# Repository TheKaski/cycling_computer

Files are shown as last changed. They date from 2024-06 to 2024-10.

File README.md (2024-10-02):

## Introduction

This project aims to offer way to turn your Arduino board into a basic cycling speedometer with the following measurement features implemented: Current speed, Average speed, Travelled distance and Cadence sensor. Additionally this project also offers 3D models for 3D printed parts including: casing of the board, casing of the sensor, holder for magnets. This code was implemented for the board: Arduino RP2040 Nano Connect with BLE support, but other boards should also be compatitible with the code with minor adjustments. Check the Hardware section for more details about my specific build.

## Contributors

<a href="https://github.com/TheKaski/cycling_computer/graphs/contributors">
  
</a>

## Supported Features

- **Speed Sensor**
- **Cadence Sensor**
- **7/8-Segment Display**
- **Current Speed**
- **Average Speed**
- **Travelled Distance**
- **BLE support for speed and cadence**

## Goals and outcomes of this project

The goals for this project were to:

1. Find interesting use case for Arduino board and develop a solution for that use case
2. Learn more about Arduino, C++ and electronics
3. Learn more about 3D printing and designing.

Outcome of this project is that I learned a lot about working with Arduino and electronics. I also learned a lot more about C++ as I decided to write the 7-segment display class from scratch. My skills on 3D printing and design were also improved by the project. I am particularily happy with the snap on bottom and top of the casing and the design which allows to print separately the bottom, casing and the top to make it easier to fit other components.

## How to use this project:

You can use this project by cloning this repo:

```
git clone https://github.com/TheKaski/cycling_computer.git
```

Open the file cycling_computer.ino with the Arduino IDE and upload to your board.
The Arduino codefile cycling_computer.ino uses the custom made display class for the segment display, however with small adjustments you can also configure the code to use any other display class if you want to. You can also try to develop your own display class inside the Display.cpp and .h files if you want to learn about Arduino, C++, Display libraries and Github contributions. However this is not expected by the nature of this project being only a hobby project. You can adjust the .ino file according to your needs relatively easily.

## Hardware used

Board: Arduino RP2040 Nano Connect

Battery: 9V battery

Hall effect sensor: Bipolar hall effect sensor SS441A

Display: Four digit segment display with decimal points(8-segments) 5611AS

PushButton: Momentary 4-pin mini pushbutton

Resistors(Ω): 10K, 680, 220

Magnets: 2pcs small neodymium magnets

3D filament: PLA

## Libraries required:

- ArduinoBLE
- avr/dtostrf

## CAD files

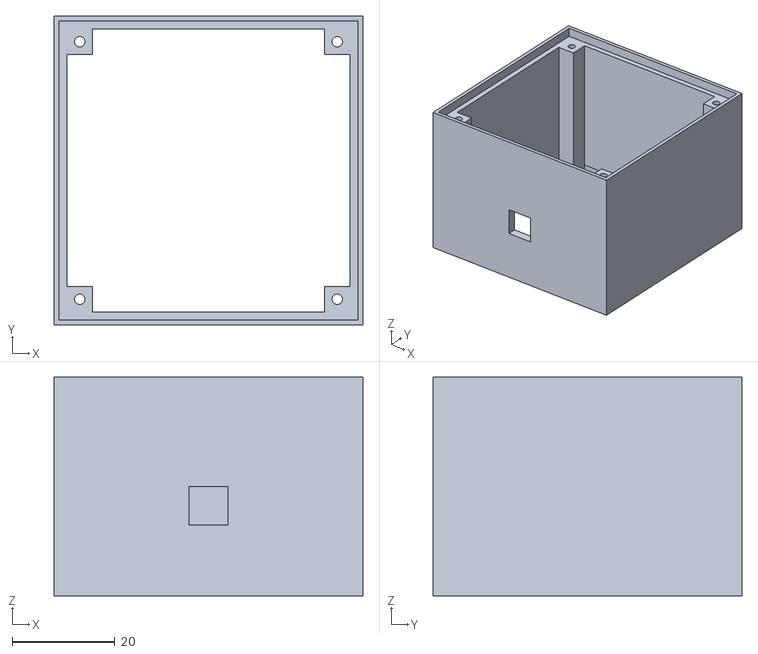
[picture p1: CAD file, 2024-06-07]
models/Case.stl
60.0 x 60.0 x 42.5

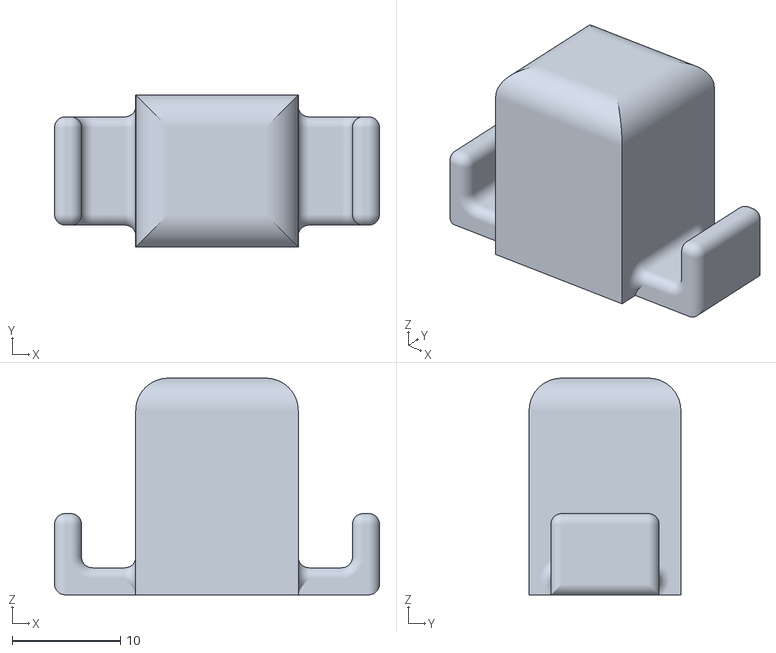
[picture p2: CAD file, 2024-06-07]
models/Sensor.stl
30.0 x 14.0 x 20.0

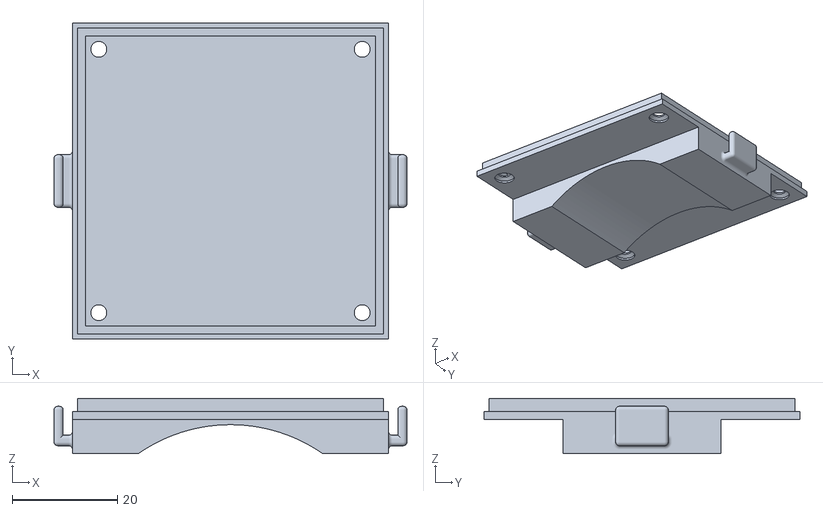
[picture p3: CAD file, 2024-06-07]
models/Bottom.stl
67.0 x 60.0 x 10.5

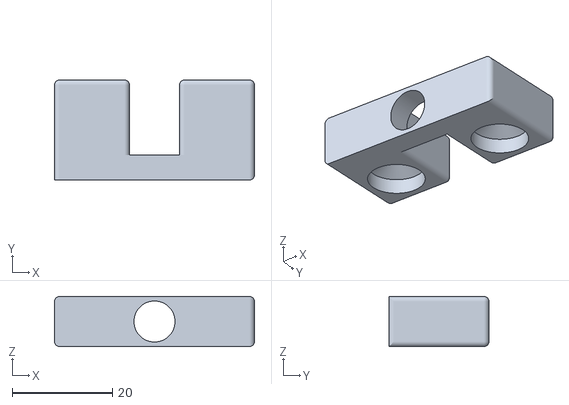
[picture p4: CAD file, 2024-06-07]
models/Magnets.stl
40.0 x 20.0 x 10.0

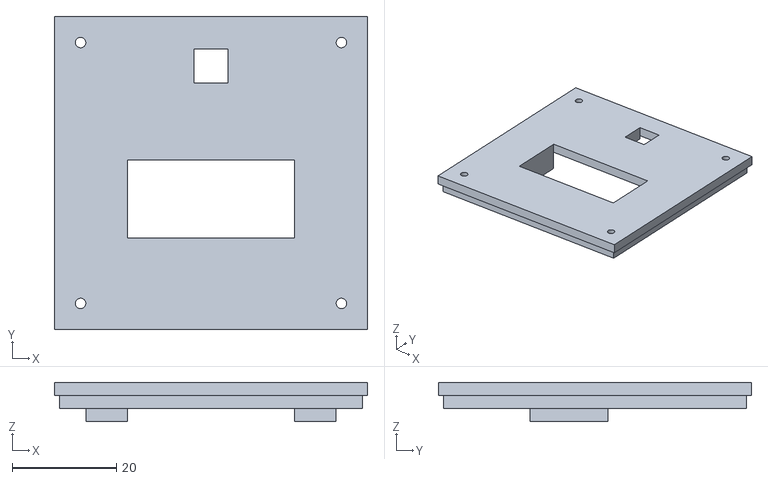
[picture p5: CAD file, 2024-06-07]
models/Top.stl
60.0 x 60.0 x 7.50

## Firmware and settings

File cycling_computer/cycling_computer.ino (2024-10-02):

#include "Display.h"
#include <avr/dtostrf.h>
#include <ArduinoBLE.h>

// Active sensors
const bool speedSensorActive = true;
const bool cadenceSensorActive = false;

// Pins
const int speedSensor = 5; //Adjust these values based on your circuit
const int navButton = 4;
const int cadenceSensor = 0; //CadenceSensor can be configured by using this pinvariable.

// Clock variables for speed
bool clockEnabled = false;  // Variable for determining the speedSensor clock state
volatile unsigned long int T1, T2, timeDiff; // Time values used by the speedsensor

// Clock variables for cadence
bool cadenceClockEnabled = false;
volatile unsigned long int cadenceT1, cadenceT2; // Time values used by the cadenceSensor

// Navigation indexes:
volatile int navIndex = 0; 
const int maxIndex = 2; // adjust this variable based on how many variables you want to show on screen.

// Bicycle  specific settings:
const float wheelSize = 27.5; // Wheel size in inches you want to adjust this based on your bike
const float wheelCircumference = wheelSize * 3.1415926535897932384626433832795 * 2.54 / 100; // Wheel circumference in m calculated based on your wheelsize

// Additional settings
const int screenRefreshRate = 1000; // Screen refresh rate in ms
const int timeOut = 8000; // Timeout for detecting stopped state which will set the current speed back to 0

// Metrics:
volatile float speed = 0;  // Speed in km/h
volatile float distance = 0;  // distance tracked in meters
volatile float avgSpeed = 0;  // average speed in km/h
volatile float time_s = 0;  // time in seconds is unused for now.
volatile float cadence = 0;
volatile unsigned long rotationsCount = 0; // keeping a record of the recorded rotations to calculate average speed and the travelled distance
volatile unsigned long crankRotationsCount = 0;

// NavButton:
bool buttonPressed = false;
unsigned long buttonPressTime = 0;

//Setup display variables:   
const int numOfDigits = 4;
const int numOfSegments = 8;      
int digitPins[numOfDigits] = {6, 9, 10, 12}; // {Dig1, Dig2, Dig3, Dig4} 
int segmentPins[numOfSegments] = {7, 11, 15, 17, 18, 8, 14, 16}; // { A, B, C, D, E, F, G, DP}

// BLE Service:
BLEService speedCadenceService("1816"); // Standard Cycling Speed and Cadence Service
BLECharacteristic speedCadenceMeasurementChar("2A5B", BLENotify, 11); // Measurement characteristics
BLEDevice central;

// Initialize the display
sevSegmentDisplay segmentDisplay(numOfDigits, digitPins, numOfSegments, segmentPins);
void setup() {
  Serial.begin(9600);  // Start serial communication

  // Wait for BLE service to start:
  if (!BLE.begin()) {
    Serial.println("Starting ble service failed");
    while(1);
  }

  // Set device name and advertise the service
  BLE.setLocalName("SpeedCadenceSensor");
  BLE.setAdvertisedService(speedCadenceService);
  // Add characteristics to the service
  speedCadenceService.addCharacteristic(speedCadenceMeasurementChar);
  BLE.addService(speedCadenceService);
  // Start advertising
  BLE.advertise();

  //Print user info to serial
  Serial.print("Wheel circumference in m: ");
  Serial.println(wheelCircumference);

  pinMode(navButton, INPUT); // Initialize the navbutton as input 
 
  //Attatch interrupt to SpeedSensor if set to active:
  if(speedSensorActive) 
  {
    pinMode(speedSensor, INPUT); // Initialize the speedSensor pin as an input:
    attachInterrupt(digitalPinToInterrupt(speedSensor), speedSensorInterrupt, LOW);
  }
  
  //Attatch interrupt to CadenceSensor if set to active:
  if(cadenceSensorActive)
  {
    pinMode(cadenceSensor, INPUT);
    attachInterrupt(digitalPinToInterrupt(cadenceSensor), cadenceSensorInterrupt, LOW); //Uncomment this line for the cadence
  }

  //Start the display
  segmentDisplay.begin();
}
void loop() {

  // Check for BLE central device connection
  if (!central) {
    central = BLE.central();
    if (central) {
      Serial.print("Connected to central: ");
      Serial.println(central.address());
    }
  } else if (!central.connected()) {
    Serial.print("Disconnected from central: ");
    Serial.println(central.address());
    central = BLEDevice(); // Reset central device
  }

  // Check wheter the wheel is stopped or not
  checkTime();
  // Show the correct variable on screen
  updateDisplayValue(); 
  //Handle any navigation buttonpresses:
  handleNavigationButton();

  //If the central device is connected, send data:
  if(central.connected()) {
    sendSpeedCadenceData();
  }
}
// Function for updating what value shown on the screen.
void updateDisplayValue() 
{
  switch (navIndex) {
    case 0:
      // Display avgSpeed
      displayValue(speed);
      break;
    case 1:
      // Display the current speed
      displayValue(avgSpeed);
      break;
    case 2:
      // Display the current distance travelled
      // The distance is only calculated when we are showing it on the screen 
      distance = rotationsCount * wheelCircumference;
      displayValue(distance / 1000); // Convert meters to km and display the result
      break;
    // Add more variables to be shown for example cadence
    default:
      break;
  }
}

// Function for displaying given value on the display with correct dataformat:
void displayValue(float value)
{
  char result[6];
  dtostrf(value, 6, 2, result);
  segmentDisplay.show(result, 6);
}

// Function for handling the navigation logic of the navButtonButton
void handleNavigationButton()
{

  // Here we "record" the button press when detected:
  if(digitalRead(navButton) == HIGH && !buttonPressed)
  {
    buttonPressed = true;
    buttonPressTime = millis();
    return;
  }
  // When button goes to LOW when it is pressed we take second time and estimate the result:
  if(digitalRead(navButton) == LOW && buttonPressed)
    {
      // Calculate how long was the press:
      unsigned long pressDuration = millis() - buttonPressTime;
      if(pressDuration < 1000 )
      { // Short press for navigation:
        handleNavigationPress();
      } else if (pressDuration > 2000)
      { // Long press is for resetting variables
        resetMetrics();
      }
      // Always set the flag back to false
      buttonPressed = false;
    }
}

void handleNavigationPress()
{
  if(navIndex == maxIndex) {
          navIndex = 0;
          displayNavigationBar(navIndex);
          return;
        }
        navIndex = navIndex+1;
        displayNavigationBar(navIndex);
}
//Function for resetting the metrics on runtime
// Used to clear for example metrics recorded before starting a ride (taking bike out and setting it up)
void resetMetrics()
{
  speed = 0;
  distance = 0;
  avgSpeed = 0;
  time_s = 0;
  cadence = 0;  
  rotationsCount = 0;
  crankRotationsCount = 0;
  //Reset the clocks
  clockEnabled = false;
  cadenceClockEnabled = false;
  // Show the reset by re begining the diplay:
  segmentDisplay.begin();
}

// Function for displaying a simple navindex on the screen based on navIndex.
// This is a workaround for now due to the way the ShowFunction is defined.
// There might be need to update the display library so that it would allow to show strings directly
void displayNavigationBar(int navIndex)
{
  char navBar[4];
  // Populate the navBar array based on navIndex
  for (int i = 0; i < 4; i++) {
    if (i <= navIndex) {
      navBar[i] = '_'; // Set the position indicated by navIndex to '_'
    } else {
      navBar[i] = ' '; // Set other positions to ' ' (space)
    }
  }
  // Show the navigation bar on the segment display
  segmentDisplay.show(navBar, 4);
  delay(200);
  return;
}

//Function for checking elapsed time used to detect wheter wheel has stopped
void checkTime()
{
  //Clock needs to be in enabled state
  if(clockEnabled)
  {
    T2 = millis();
    //If elapsedTime is greater than timeout value we set the speed back to zero
    if(T2-T1 > timeOut)
    {
     speed = 0;
    }
  }
}

// Function for calculating and returning the speed in km/h based on time measurement in seconds
float calculateSpeed(unsigned long int spinTime) {

  // Calculates speed by dividing wheel circumference by time in seconds and converting to km/h
  float calculatedSpeed = wheelCircumference / (spinTime / 1000.0) * 3.6; // Speed in km/h
  return calculatedSpeed;

}
// Function for calculating rpm/cadence based on time in seconds
float calculateCadence(unsigned long int rotationTime) {
  // Calculate the rpm by dividing 60 seconds with the rotationTime
  float rpm = 60.0 / rotationTime;
  return rpm;
}

//Interrupt function for the speedsensor. It will start a clock by taking time T1 when magnetic pulse is detected and set clockenabled to True
// When the clock is enabled and the pulse is detected second time the wheel has turned one full revolution and we take new time and calculate the difference.
// based on the difference the speed can be calculated and updated based on new value.
// The T2 value is then used as new value for T1 and the clock is enabled again.
void speedSensorInterrupt() {
  //Take end time when clock status is enabled
  if(clockEnabled)
  {
    T2 = millis();
    timeDiff = T2-T1;
    //If the timeDifference is greater then 1ms calculate speed from it
    if( timeDiff > 1 )
    {
      clockEnabled = false;
      // Update the number of rotations
      rotationsCount++;
      float new_speed = calculateSpeed(timeDiff); //Update the speed value
      speed = new_speed;
      // To keep up the average speed we implement a running  average formula to avoid overflow of the sum of speed values and constant large number division
      avgSpeed = avgSpeed + (new_speed-avgSpeed) / rotationsCount;
    }
    //when the clock is enabled use the T2 trigger time to start a new clock:
    T1 = T2;
    clockEnabled = true;
    return;
  }
  //Take T1 Always when clock status is not enabled
  T1 = millis();
  clockEnabled = true;
}

//Interrupt function for cadence sensor. Measures the time of one full revolution and estimates the cadence in rpm with calculateCadence function.
void cadenceSensorInterrupt() {
  //Take end time when clock status is enabled
  if(cadenceClockEnabled)
  {
    cadenceT2 = millis();
    float deltaTime = cadenceT2-cadenceT1;
    //If the timeDifference is greater then 1ms calculate speed from it
    if( deltaTime > 1 )
    {
      clockEnabled = false;
      // calculate the rpm based on the deltaTime:
      cadence = calculateCadence(deltaTime);
    }
    crankRotationsCount++;
    cadenceT1 = cadenceT2;
    cadenceClockEnabled;
    return;
  }
  //Take T1 Always when clock status is not enabled (Start new clock when clock is not enabled)
  cadenceT1 = millis();
  cadenceClockEnabled = true;
}

// Functions for BLE communication:

//Function for sending data for Speedsensor, Cadence sensor or both when they are set to be active
//This function uses the BLE standard speedCadence characteristics to communicate to third party BLE fitnness applications
void sendSpeedCadenceData() {
  uint8_t flags = 0;
  int offset = 1; // Start at the second byte for data

  uint8_t speedCadenceData[11] = {0};

  if(speedSensorActive) {
    flags |= 0x01; // Set speed data present flag
    speedCadenceData[offset++] = (uint8_t)(rotationsCount & 0xFF);
    speedCadenceData[offset++] = (uint8_t)((rotationsCount >> 8) & 0xFF);
    speedCadenceData[offset++] = (uint8_t)((rotationsCount >> 16) & 0xFF);
    speedCadenceData[offset++] = (uint8_t)((rotationsCount >> 24) & 0xFF);
    speedCadenceData[offset++] = (uint8_t)(T1 & 0xFF);
    speedCadenceData[offset++] = (uint8_t)((T1 >> 8) & 0xFF);
  }

  if(cadenceSensorActive) {
    flags |= 0x02;
    speedCadenceData[offset++] = (uint8_t)(crankRotationsCount & 0xFF);
    speedCadenceData[offset++] = (uint8_t)((crankRotationsCount >> 8) & 0xFF);
    speedCadenceData[offset++] = (uint8_t)(cadenceT1 & 0xFF);
    speedCadenceData[offset++] = (uint8_t)((cadenceT1 >> 8) & 0xFF);
  }

  // Set flags byte
  speedCadenceData[0] = flags;

  // Write data to characteristic
  speedCadenceMeasurementChar.writeValue(speedCadenceData, offset);

}

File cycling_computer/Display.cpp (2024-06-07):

/* display.cpp -- Library for all the  display components */
#include "Display.h"
#include "Segments.h"

// 7-Segment Display start:
// PUBLIC 
sevSegmentDisplay::sevSegmentDisplay(int numOfDigits, int* digitPins, int numOfSegments, int* segmentPins) 
{
    this->numOfDigits = numOfDigits;  
    this->numOfSegments = numOfSegments;
    this->digitPins = digitPins;
    this->segmentPins = segmentPins; //If the decimal segment is defined 8 segments can be used
}
//Set the pins ready to be used
void sevSegmentDisplay::begin() 
{
  setupDisplay();
  startupAnimation(); // Screen test animation that all the segments are correctly lighted up
  
}

void sevSegmentDisplay::show(char data[], int size, int delaytime) 
{
  //Function for showing given data on screen. Output will show max ammount of characters that can be fitted in the provided display at once
  bool refresh = false;
  int T1 = millis();

  // This loop will use the delaytime to determine the time each digit is displayed.
  while(refresh == false) 
  {
    int digit = 0;
    int dataIndex = 0;
    //Prints data to digits from left to right
    while(dataIndex < size )  
    {
      //Return if display gets full before the end of data[]
      if(digit >= this->numOfDigits)
      {
        break;
      }
      //If the next character is dot append it to this digit and skip the dot next round
      if(data[dataIndex+1] == '.')
      {
        showDigit(this->digitPins[digit], data[dataIndex], true);
        dataIndex++; //Skip the dot in the data
      } else {
        showDigit(this->digitPins[digit], data[dataIndex]);
      }
      digit++; //Move to next digit
      dataIndex++; //Move to next data char
    }
    int T2 = millis();
    if(T2-T1 > delaytime) 
    {
      refresh = true;
    } 
  }
}
// PRIVATE:
void sevSegmentDisplay::showDigit(int digitPin, char dataChar, bool hasDot)
{
  //show digit will turn on the segments for the specified character and then light up the full digit
  //This function will use specified charactertable to translate characters to segments
  uint8_t charToSegments = SevenSegmentASCII[dataChar-32];  //get the segmentcode with the given datachar
   //Turn the segments on
  turnONSegments(charToSegments, hasDot);
  //Turn on the digit by setting the digitPin LOW 
  digitalWrite(digitPin, LOW); //The digit lights up when segments are HIGH and digit is LOW
  delay(6); //Delay for seeing the light
  //Turn the segments off
  turnOFFSegments();
  digitalWrite(digitPin, HIGH);
}
// Function for initializing the screen component
void sevSegmentDisplay::setupDisplay()
{
   //Set the digitPins  as OUTPUTS:
  for(int pin = 0; pin < this->numOfDigits; pin++){
    pinMode(this->digitPins[pin], OUTPUT);
    digitalWrite(this->digitPins[pin], HIGH);
  }
  //Set the segmentPins as OUTPUTS:
  for(int pin = 0; pin < this->numOfSegments; pin++){
    pinMode(this->segmentPins[pin], OUTPUT);
    digitalWrite(this->segmentPins[pin], LOW);
  }
}

void sevSegmentDisplay::turnONSegments(uint8_t segments, bool hasDot)
//Function for turning on specified segments on the display
{
  //Turn on the segments
  for(int i = 0; i < this->numOfSegments; i++)
  {
    int bitValue = bitRead(segments, i); //NOTE: Bit read reads from least-significant(rightmost bit) to most significant
    int pin = this->segmentPins[i];

    if(bitValue == 1)
    {
      digitalWrite(pin,HIGH); //Turn on the segment
    } else {
      digitalWrite(pin,LOW); //Turn off the segment
    } 
  }
  //Turn on the dot segment when hasdot is set to True and nummber of segments is greater than 7 (8th segment is the decimal point)
  if(hasDot == true && this->numOfSegments > 7){
    digitalWrite(this->segmentPins[this->numOfSegments-1],HIGH);
  }
}

void sevSegmentDisplay::turnOFFSegments()
//Function for clearing the screen by turning OFF all the segments on the display
{
  //Turn off the segments
  for(int i = 0; i < this->numOfSegments; i++)
  {
    int pin = this->segmentPins[i];
    digitalWrite(pin, LOW); //Turn off this segment
  }
}

void sevSegmentDisplay::startupAnimation()
//Function for showing certain data sequence on display mainly in the beginning of the program UNNECESSARY BUT FUN
{
  char dataChar = '8'; //Animation character
  uint8_t charToSegments = SevenSegmentASCII[dataChar-32];
  //Turn on all the digits
  for(int pin = 0; pin < this->numOfDigits; pin++){
    digitalWrite(this->digitPins[pin], LOW);
  }
  //Turn on the character segments
  turnONSegments(charToSegments);
  delay(400);
  //Turn off and back on all the digits with a delay
  for(int pin = 0; pin < this->numOfDigits; pin++){
    digitalWrite(this->digitPins[pin], HIGH);
    delay(200);
    digitalWrite(this->digitPins[pin], LOW);
  }
  //Togle the segments on and off with delays
  turnOFFSegments();
  delay(200);
  turnONSegments(charToSegments);
  delay(200);
  turnOFFSegments();
  delay(100);
  turnONSegments(charToSegments);
  delay(200);
  turnOFFSegments();
  //Toggle the digits back off
  for(int pin = 0; pin < this->numOfDigits; pin++){
    digitalWrite(this->digitPins[pin], HIGH);
  }
}
//7-Segment Display end

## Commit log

2023-07-07 New formatting & added interrupt
2023-07-07 Removed interrupt
2023-07-07 Added wheel size
2023-07-07 Added wheelsize and circumference
2023-07-23 Changed speedSensor pin to 2
    Arduino uno doesn't support interrupts on pin A2
    [cycling_computer.ino]
2024-06-07 The first release merge dev to main (#16)
    * Added .gitignore for hidden files and dirs
    * Added interrupt function for the clock
    * Added filter fortimevalues
    * Started the library for displays with 7-segment class
    * Cleaned non-interrupt version parts out
    * Added calculated statistics variables
    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
    [Bottom.stl, Case.stl, Magnets.stl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]
2024-10-02 Dev (#18)
    * Added function that calculates speed in km/h
    * Changed loop to display speed instead of spinTime
    * Display class code compiles now
    * initialized 7seg begin() function
    * Removed ledPin since its not used
    * Added segment to ascii conversion table
    * Sev segment feature (#8)
    * Added new features to main program
    * Debugging the display
    * Debugging continues
    * Swapped somepins
    * Ascii in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
    [cycling_computer.ino]
